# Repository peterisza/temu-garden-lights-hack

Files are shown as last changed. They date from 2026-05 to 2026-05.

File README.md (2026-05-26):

# Temu garden lights hack

I bought 12V-24V outdoor garden lights from Temu. Originally, they had two wires and a remote controller. I modified them to use an addressable three-wire bus (0V, data, 24V) to control them from my smart home. <a href="https://www.youtube.com/shorts/Vp0UermeDtU">Here</a>'s a short youtube video that shows the process and the result. 

Disclaimer: All electrical modifications are performed at your own risk.

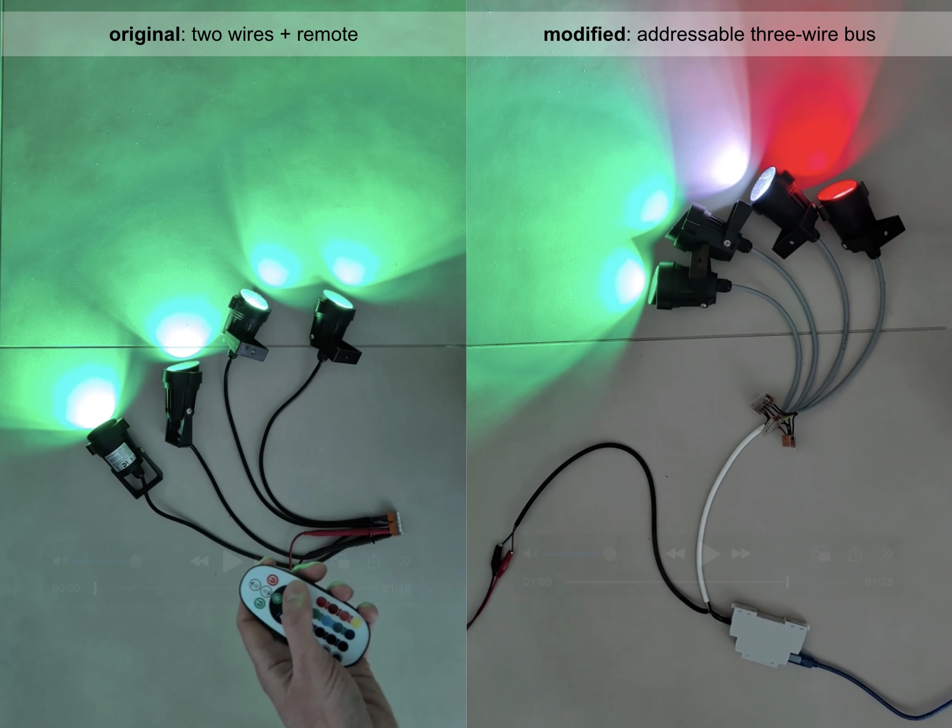
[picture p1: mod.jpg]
Modification


### Reverse engineering the lamp

<table border="0">
  <tr>
    <td valign="top">
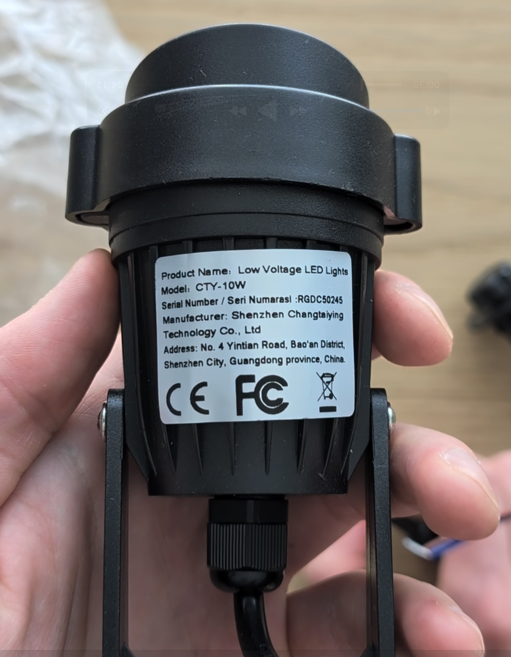
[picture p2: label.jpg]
Product Label
      
    </td>
    <td valign="top">
      <ul>
        <li><strong>Product Name:</strong> Low Voltage LED Lights</li>
        <li><strong>Model:</strong> CTY-10W</li>
        <li><strong>Serial Number / Seri Numarasi:</strong> RGDC50245</li>
        <li><strong>Manufacturer:</strong> Shenzhen Changtaiying Technology Co., Ltd</li>
        <li><strong>Address:</strong> No. 4 Yintian Road, Bao'an District, Shenzhen City, Guangdong province, China.</li>
      </ul>
    </td>
  </tr>
</table>

Originally, the lamp had an FMD FT60E122 microcontroller in an SO-14 package with the following pinout:

<table border="0">
  <th>
    <tr>
      <td>Pinout</td>
      <td>Board&nbsp;image</td>
    </tr>
  </th>
  <tr>
    <td>
      <table>
        <thead>
          <tr><th>#</th><th>Function</th></tr>
        </thead>
        <tbody>
          <tr><td>1</td><td>VDD (5V)</td></tr>
          <tr><td>2</td><td>Crystal1 (16 MHz)</td></tr>
          <tr><td>3</td><td>Crystal2</td></tr>
          <tr><td>4</td><td>radio recv</td></tr>
          <tr><td>5</td><td>Red PWM 62.8μs (10μs max)</td></tr>
          <tr><td>6</td><td>White PWM 62.8μs (49.2μs max)</td></tr>
          <tr><td>7</td><td>not connected</td></tr>
          <tr><td>8</td><td>Green PWM 62.8μs (49.2μs max)</td></tr>
          <tr><td>9</td><td>not connected</td></tr>
          <tr><td>10</td><td>not connected</td></tr>
          <tr><td>11</td><td>Blue PWM 62.8μs (49.2μs max)</td></tr>
          <tr><td>12</td><td>test point 2</td></tr>
          <tr><td>13</td><td>test point 1</td></tr>
          <tr><td>14</td><td>GND</td></tr>
        </tbody>
      </table>
    </td>
    <td valign="top">
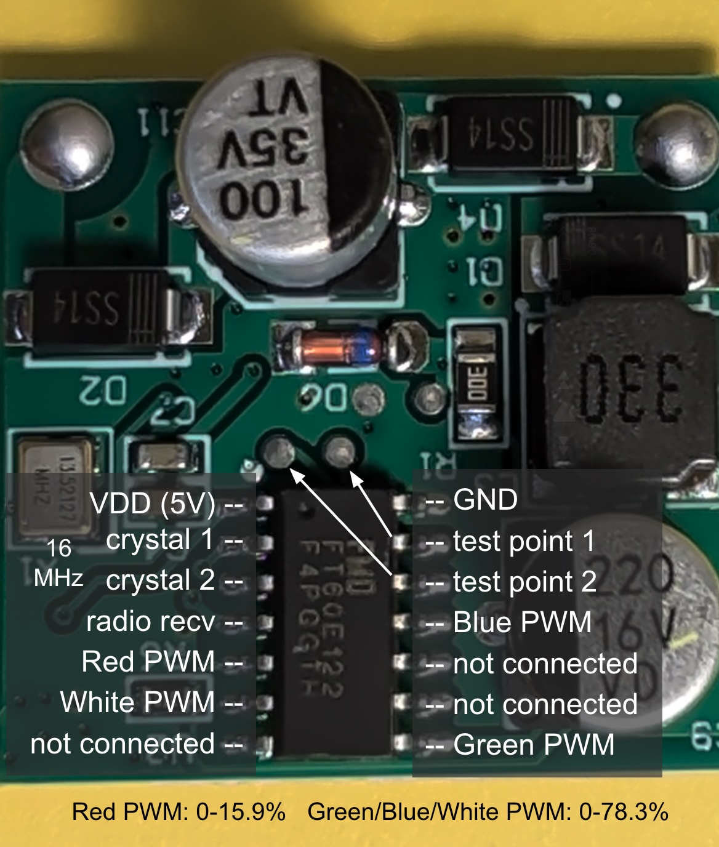
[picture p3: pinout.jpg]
pinout
      
    </td>
  </tr>
</table>

### Conversion

Luckily, this mcu is pin-compatible with the Attiny441. These are the steps I did:

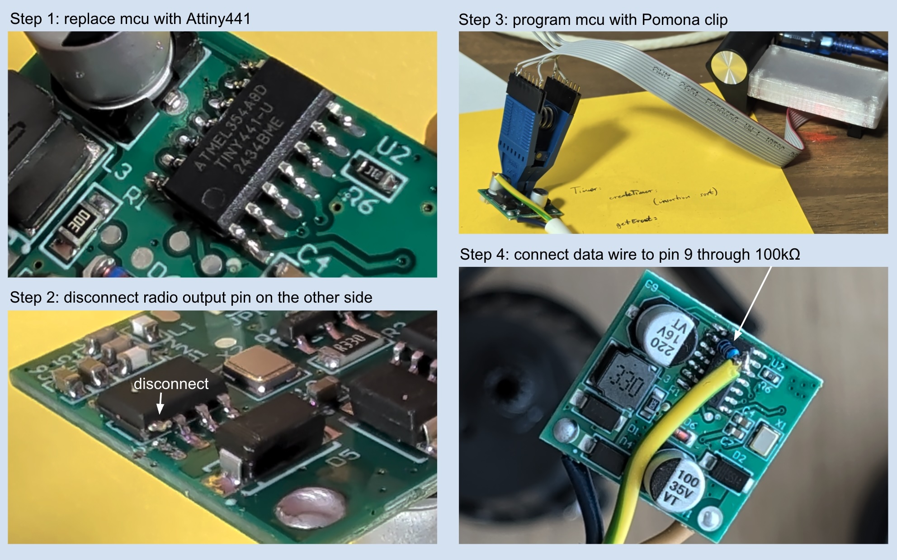
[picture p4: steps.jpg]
Steps


### Custom bus physical description
The custom bus uses three wires: 0V, data, 24V. Logical 0: < 1.5V. Logical 1: 3V-24V. Data format: 10000 baud 8N1. The data line is connected to 24V through a 20mA current limiter in the controller. Max cable length: 200m, number of nodes: 31. To send, each node can pull the data line to zero. Currently, the lamps can only receive but not send. For this reason, their address must be hardcoded during programming like so:
<code>make program LAMP_ADDRESS=0</code>.

I used a 3x0.75mm² ÖLFLEX® CLASSIC 400 P cable. It has the same diameter as the original two-wire cable, but is actually certified for outdoor use unlike the original.

### Data Frame Formats
| Size [byte] | Format A | Size [byte] | Format B |
| :---: | :--- | :---: | :--- |
| 1 | 0 < length <= 30 | 1 | length + 32 |
| max 60 | 4x4 bit RGBW | max 30 | 2x4 bit RGBW |
| 2 | fade time in ms | 2 | fade time in ms |
| 1 | brightness | 1 | brightness |
| 1 | CRC | 1 | CRC |

There must be a 2ms pause between frames.

### Colors

The firmware uses a 16kHz PWM with sigma-delta dithering. It can do gamma-correct interpolation, so the perceived brightness is linear between transitions (premium fade effect 🤩).

### The controller
The controller is a DIN rail mounted USB HID device with a cheap STM32C071 mcu. It can handle two bus lines with 30 lamps each. Build/use it at your own risk only.

My smart home server is already a Raspberry Pi which has USB, so I can just connect it. If you want standalone operation or wireless, you should build an ESP32-based controller instead of this STM32-based one.

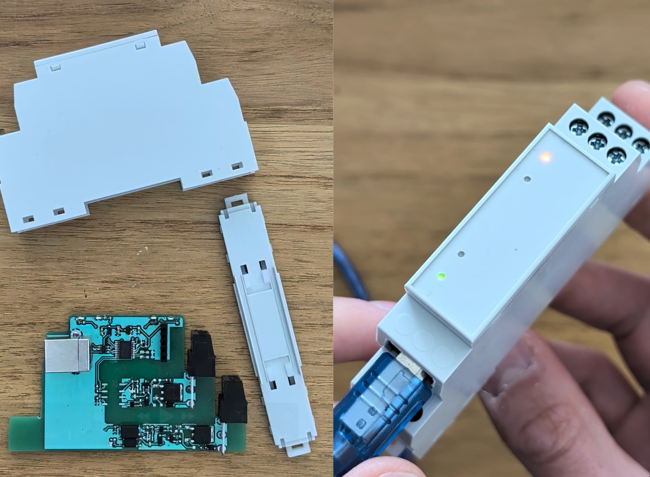
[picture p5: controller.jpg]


## Licensing

- **Software:** Licensed under the [MIT License](https://opensource.org/license/mit)
- **Hardware & Documentation:** Licensed under [CERN-OHL-P](https://ohwr.org/project/cernohl/wikis/Documents/CERN-OHL-version-2) / [CC-BY-4.0](https://creativecommons.org/licenses/by/4.0/)

Basically: feel free to use, modify, and share this project, but keep the attribution and don't sue me if something breaks.

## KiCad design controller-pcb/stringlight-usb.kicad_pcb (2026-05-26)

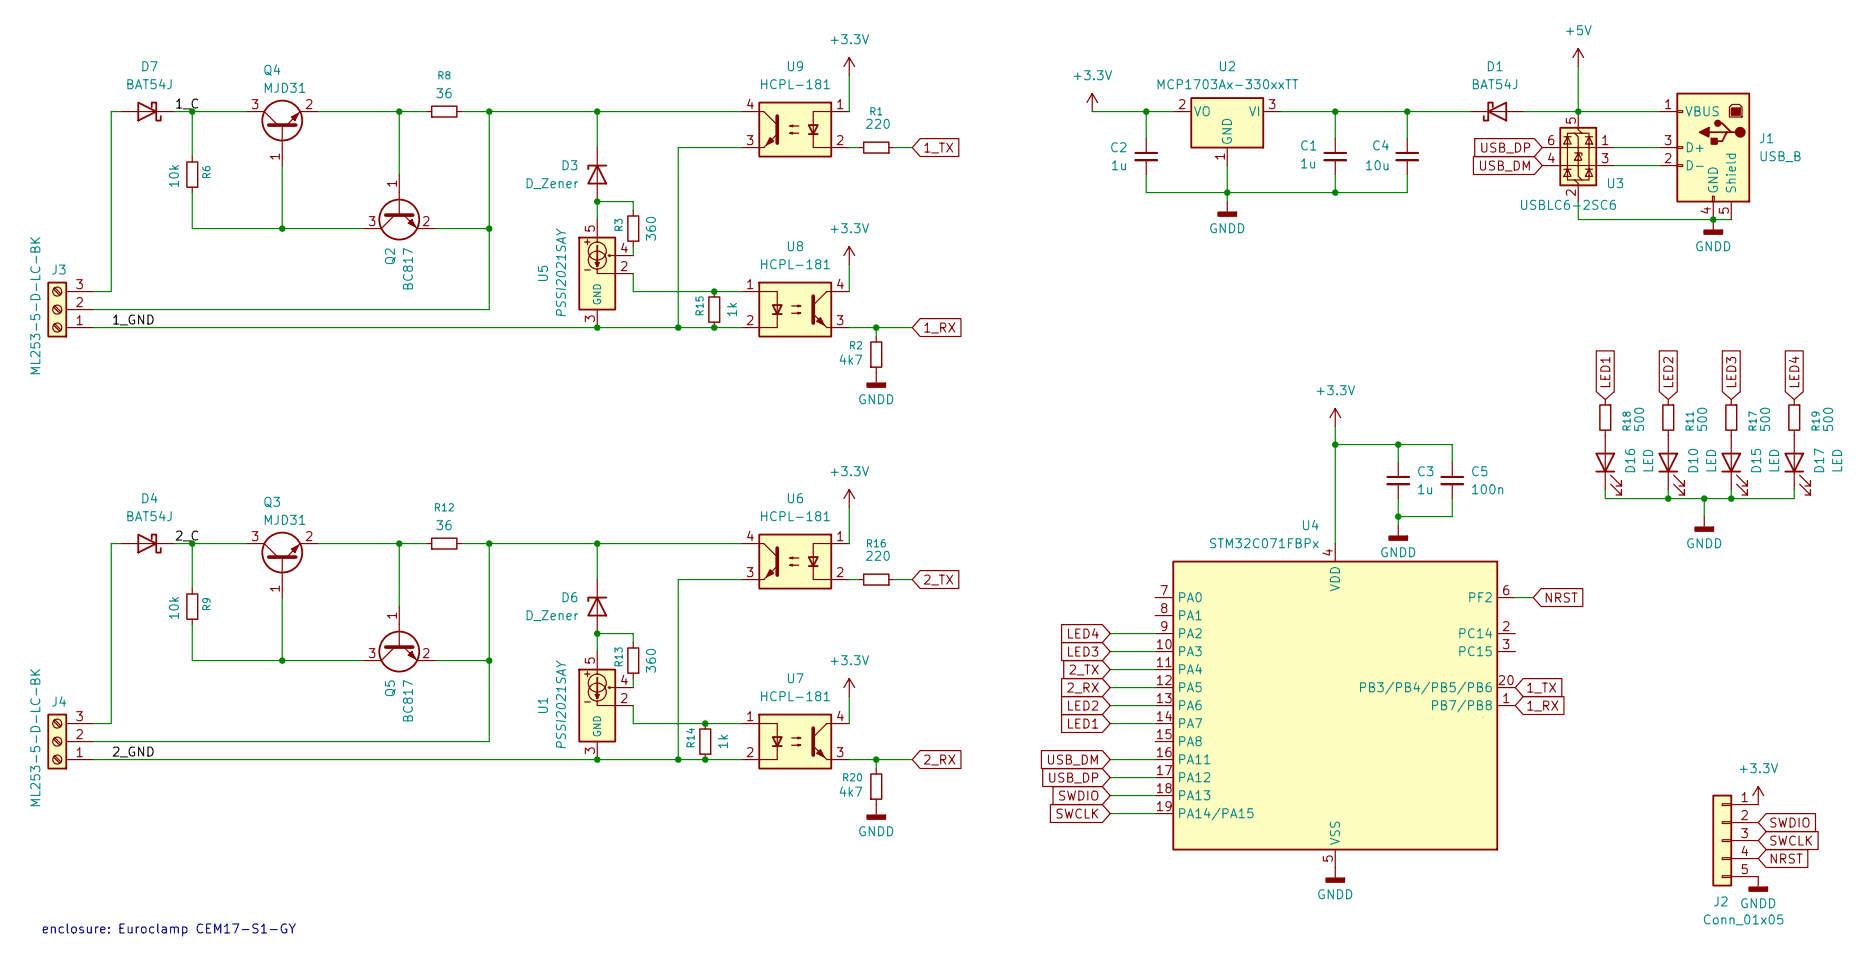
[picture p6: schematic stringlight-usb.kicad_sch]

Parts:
C1, C2, C3: 1u; C_0603_1608Metric_Pad1.08x0.95mm_HandSolder
C4: 10u; C_0805_2012Metric_Pad1.18x1.45mm_HandSolder
C5: 100n; C_0603_1608Metric_Pad1.08x0.95mm_HandSolder
D1, D4, D7: BAT54J; D_SOD-323_HandSoldering
D3, D6: D_Zener; D_SOD-123F
D10, D15, D16, D17: LED; LED_Kingbright_APA1606_1.6x0.6mm_Horizontal
J1: USB_B; USB_B_Lumberg_2411_02_Horizontal
J2: Conn_01x05; PinHeader_1x05_P2.54mm_Vertical
J3, J4: ML253-5-D-LC-BK; ML253-5-S-LC
Q2, Q5: BC817; SOT-23
Q3, Q4: MJD31
R1, R16: 220; R_0603_1608Metric_Pad0.98x0.95mm_HandSolder
R2, R20: 4k7; R_0603_1608Metric_Pad0.98x0.95mm_HandSolder
R3, R13: 360; R_0603_1608Metric_Pad0.98x0.95mm_HandSolder
R6, R9: 10k; R_0603_1608Metric_Pad0.98x0.95mm_HandSolder
R8, R12: 36; R_0603_1608Metric_Pad0.98x0.95mm_HandSolder
R11, R17, R18, R19: 500; R_0603_1608Metric_Pad0.98x0.95mm_HandSolder
R14, R15: 1k; R_0603_1608Metric_Pad0.98x0.95mm_HandSolder
U1, U5: PSSI2021SAY; SOT-353_SC-70-5
U2: MCP1703Ax-330xxTT; SOT-23
U3: USBLC6-2SC6; SOT-23-6
U4: STM32C071FBPx; TSSOP-20_4.4x6.5mm_P0.65mm
U6, U7, U8, U9: HCPL-181; SO-4_4.4x3.6mm_P2.54mm

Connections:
1_RX: R2.2, U4.1 (PB7/PB8), U8.3
1_TX: R1.1, U4.20 (PB3/PB4/PB5/PB6)
2_RX: R20.2, U4.12 (PA5), U7.3
2_TX: R16.1, U4.11 (PA4)
+3.3V: C2.1, C3.1, C5.1, J2.1, U2.2 (VO), U4.4 (VDD), U6.1, U7.4, U8.4, U9.1
+5V: D1.2 (A), J1.1 (VBUS), U3.5 (VBUS)
/1_C: D7.1 (K), Q4.3 (C), R6.2
/1_GND: J3.1, R15.1, U5.3 (GND_3), U8.2, U9.3
/2_C: D4.1 (K), Q3.3 (C), R9.2
/2_GND: J4.1, R14.1, U1.3 (GND_3), U6.3, U7.2
GNDD: C1.2, C2.2, C3.2, C4.2, C5.2, D10.1 (K), D15.1 (K), D16.1 (K), D17.1 (K), J1.4 (GND), J1.5 (Shield), J2.5, R2.1, R20.1, U2.1 (GND), U3.2 (GND), U4.5 (VSS)
LED1: R18.1, U4.14 (PA7)
LED2: R11.1, U4.13 (PA6)
LED3: R17.1, U4.10 (PA3)
LED4: R19.1, U4.9 (PA2)
NRST: J2.4, U4.6 (PF2)
unnamed: C1.1, C4.1, D1.1 (K), U2.3 (VI)
unnamed: D3.2 (A), R3.2, U5.5
unnamed: D3.1 (K), J3.2, Q2.2 (E), R8.2, U9.4
unnamed: D4.2 (A), J4.3
unnamed: D6.2 (A), R13.2, U1.5
unnamed: D6.1 (K), J4.2, Q5.2 (E), R12.2, U6.4
unnamed: D7.2 (A), J3.3
unnamed: D10.2 (A), R11.2
unnamed: D15.2 (A), R17.2
unnamed: D16.2 (A), R18.2
unnamed: D17.2 (A), R19.2
unnamed: J1.3 (D+), U3.1 (I/O1)
unnamed: J1.2 (D-), U3.3 (I/O2)
unnamed: Q2.1 (B), Q4.2 (E), R8.1
unnamed: Q2.3 (C), Q4.1 (B), R6.1
unnamed: Q3.1 (B), Q5.3 (C), R9.1
unnamed: Q3.2 (E), Q5.1 (B), R12.1
unnamed: R1.2, U9.2
unnamed: R3.1, U5.4
unnamed: R13.1, U1.4
unnamed: R14.2, U1.2, U7.1
unnamed: R15.2, U5.2, U8.1
unnamed: R16.2, U6.2
SWCLK: J2.3, U4.19 (PA14/PA15)
SWDIO: J2.2, U4.18 (PA13)
USB_DM: U3.4 (I/O2), U4.16 (PA11)
USB_DP: U3.6 (I/O1), U4.17 (PA12)

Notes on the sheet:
enclosure: Euroclamp CEM17-S1-GY

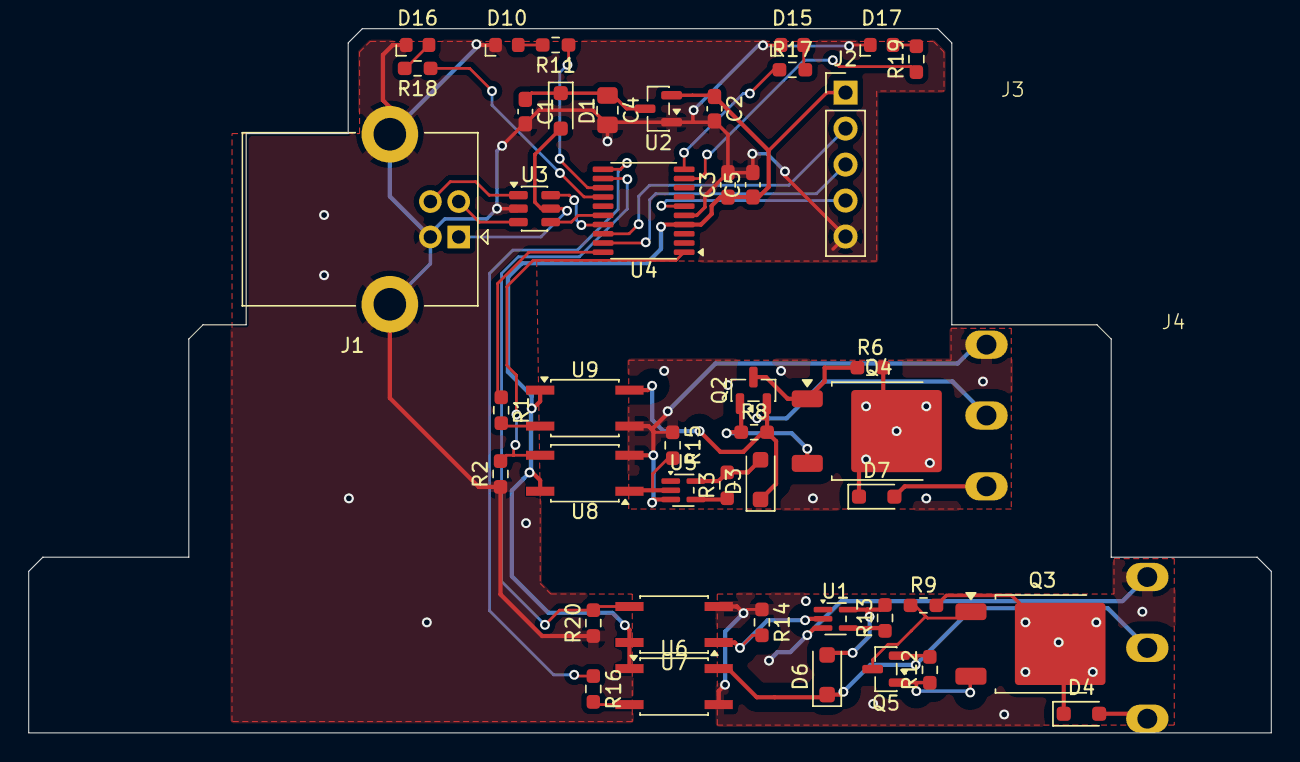
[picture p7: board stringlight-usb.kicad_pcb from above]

Board: 2 copper layers, 87.7 x 49.7 mm, 47 parts (0 on the bottom side), 43 nets.

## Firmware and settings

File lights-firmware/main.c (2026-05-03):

// Attiny441

#define F_CPU 16000000UL
#include <avr/io.h>
#include <avr/interrupt.h>
#include <avr/pgmspace.h>
#include <util/delay.h>
#include <stdint.h>

#define S16_TO_S32_SHIFT(x) ((int32_t)(x) >> 16)
#define U8_TO_U16(x) ((uint16_t)(x))
#define U8_TO_U16_SHIFT(x) ((uint16_t)(x) << 8)

#ifndef LAMP_ADDRESS
#error "LAMP_ADDRESS nincs definialva. Forditsd igy: -DLAMP_ADDRESS=<0..255> (Makefile: LAMP_ADDRESS=...)"
#endif

static const uint8_t bus_address = (uint8_t)(LAMP_ADDRESS);

void io_init() {
	// --- PWM kimenet (PA5 / TOCC4) ---

	DDRA |= (1 << PA3); // PA3 kimenet
	DDRA &= ~(1 << PA4);

	// 1. Lábak kimenetként (PB2, PA7, PA2, PA5)
	DDRA |= (1 << DDA7) | (1 << DDA5) | (1 << DDA2);
	DDRB |= (1 << DDB2);
    
	//PORTA |= (1 << PA4);
}

/* Timer1 overflow tick: Fast PWM-nél f_ov = F_CPU / (TOP+1). A PWM_MAX úgy van választva,
   hogy a korábbi phase-correct időalap (4 tick/ms) megmaradjon. */
static volatile uint8_t g_t1_ticks;
static volatile uint8_t g_last_rx_tick;

static void timer0_init_1ms(void) {
	PRR &= ~(1 << PRTIM0);

	/* CTC: TOP = OCR0A, compare match A interrupt
	   16 MHz, prescaler 64 => 250 kHz tick => OCR0A=249 => 1 kHz (1 ms) */
	TCCR0A = (1 << WGM01);
	TCCR0B = (1 << CS01) | (1 << CS00);
	OCR0A = 249;
	TCNT0 = 0;
	TIFR0 = (1 << OCF0A);
	TIMSK0 |= (1 << OCIE0A);
}

/* TCNT0/1/2 = 0 futó órával is rendben; cli a 16 bites TCNT1/2 írás miatt kell (TEMP regiszter).
 * A TIFR flag bitek ettől nem törlődnek — ha zavar a régi beakadás, azt külön kell 1-gyel írni. */
void timers_sync_counters_zero(void) {
	uint8_t sreg = SREG;
	cli();
	TCNT0 = 0;
	TCNT1 = 0;
	TCNT2 = 0;
	SREG = sreg;
}

/* Fast PWM TOP = PWM_MAX => periódus (tick) = (PWM_MAX+1) CPU ciklus prescaler=1-nél */
#define PWM_MAX 1000U
#define PWM_DITHERING_BITS 4
#define PWM_DITHERING_FACTOR (1 << PWM_DITHERING_BITS)
#define UART_SILENCE_TICKS_2MS (4U)

#define NUM_CHANNELS 4

#define PWM_CHANNEL_RED 0
#define PWM_CHANNEL_GREEN 1
#define PWM_CHANNEL_BLUE 2
#define PWM_CHANNEL_WHITE 3

volatile uint16_t pwm_output[NUM_CHANNELS] = {0, 0, 0, 0};
volatile uint16_t pwm_output_dithered[NUM_CHANNELS] = {0, 0, 0, 0};
volatile uint8_t pwm_fraction[NUM_CHANNELS] = {0, 0, 0, 0};
volatile uint8_t pwm_error[NUM_CHANNELS] = {0, 0, 0, 0};

volatile int32_t channels[NUM_CHANNELS];
volatile int32_t targets[NUM_CHANNELS];
volatile int32_t step[NUM_CHANNELS];

volatile int32_t brightness = 0;
volatile int32_t brightness_target = 0;
volatile int32_t brightness_step = 0;

static const uint16_t channel_max[NUM_CHANNELS] = {
	160U,
	780U,
	780U,
	780U,
};


void set_pwm_registers() {
	OCR1A = pwm_output_dithered[PWM_CHANNEL_RED];
	OCR1B = pwm_output_dithered[PWM_CHANNEL_WHITE];
	OCR2A = pwm_output_dithered[PWM_CHANNEL_BLUE];
	OCR2B = pwm_output_dithered[PWM_CHANNEL_GREEN];
	TCCR1A = (TCCR1A & (uint8_t)~((1 << COM1A1) | (1 << COM1B1)))
		| (pwm_output_dithered[PWM_CHANNEL_RED] != 0 ? (1 << COM1A1) : 0) | (pwm_output_dithered[PWM_CHANNEL_WHITE] != 0 ? (1 << COM1B1) : 0);
	TCCR2A = (TCCR2A & (uint8_t)~((1 << COM2A1) | (1 << COM2B1)))
		| (pwm_output_dithered[PWM_CHANNEL_BLUE] != 0 ? (1 << COM2A1) : 0) | (pwm_output_dithered[PWM_CHANNEL_GREEN] != 0 ? (1 << COM2B1) : 0);
}


void pwm_init() {
	// 2. TOCP Pin Mux beállítása (Timer kimenetek lábakhoz rendelése)
	// TOCC7:OC1A, TOCC6:OC1B, TOCC4:OC2B, TOCC1:OC2A
	TOCPMSA1 = (0<<TOCC7S1) | (1<<TOCC7S0) | (0<<TOCC6S1) | (1<<TOCC6S0) | (1<<TOCC4S1) | (0<<TOCC4S0);
	TOCPMSA0 = (1<<TOCC1S1) | (0<<TOCC1S0);

	// TOCC kimenetek engedélyezése
	TOCPMCOE = (1<<TOCC7OE) | (1<<TOCC6OE) | (1<<TOCC4OE) | (1<<TOCC1OE);

	// 3. Timer1 beállítása (PB2 és PA7) - Fast PWM, Mode 14, TOP = ICR1
	TCCR1A = (1 << COM1A1) | (1 << COM1B1) | (1 << WGM11);
	TCCR1B = (1 << WGM13) | (1 << WGM12) | (1 << CS10);
	ICR1 = PWM_MAX-1;
	TIMSK1 |= (1 << TOIE1); /* időalap: TIMER1_OVF_vect */

	// 4. Timer2 beállítása (PA2 és PA5) - Fast PWM, TOP = ICR2 (WGM2[2:0]=111)
	TCCR2A = (1 << COM2A1) | (1 << COM2B1) | (1 << WGM21) | (1 << WGM20);
	TCCR2B = (1 << WGM22) | (1 << CS20);
	ICR2 = PWM_MAX-1;

	// 5. Példa kitöltési tényezők (0 - 500 tartományban)
	set_pwm_registers();
}




#define UART_BUFFER_SIZE 70
static volatile uint8_t uart_buffer[UART_BUFFER_SIZE];
static volatile uint8_t uart_buffer_length;

/* CRC-8/ATM (poly 0x07, init 0x00, no xorout), table-driven, MSB-first */
static const uint8_t crc8_atm_table[256] PROGMEM = {
	0x00, 0x07, 0x0E, 0x09, 0x1C, 0x1B, 0x12, 0x15, 0x38, 0x3F, 0x36, 0x31, 0x24, 0x23, 0x2A, 0x2D,
	0x70, 0x77, 0x7E, 0x79, 0x6C, 0x6B, 0x62, 0x65, 0x48, 0x4F, 0x46, 0x41, 0x54, 0x53, 0x5A, 0x5D,
	0xE0, 0xE7, 0xEE, 0xE9, 0xFC, 0xFB, 0xF2, 0xF5, 0xD8, 0xDF, 0xD6, 0xD1, 0xC4, 0xC3, 0xCA, 0xCD,
	0x90, 0x97, 0x9E, 0x99, 0x8C, 0x8B, 0x82, 0x85, 0xA8, 0xAF, 0xA6, 0xA1, 0xB4, 0xB3, 0xBA, 0xBD,
	0xC7, 0xC0, 0xC9, 0xCE, 0xDB, 0xDC, 0xD5, 0xD2, 0xFF, 0xF8, 0xF1, 0xF6, 0xE3, 0xE4, 0xED, 0xEA,
	0xB7, 0xB0, 0xB9, 0xBE, 0xAB, 0xAC, 0xA5, 0xA2, 0x8F, 0x88, 0x81, 0x86, 0x93, 0x94, 0x9D, 0x9A,
	0x27, 0x20, 0x29, 0x2E, 0x3B, 0x3C, 0x35, 0x32, 0x1F, 0x18, 0x11, 0x16, 0x03, 0x04, 0x0D, 0x0A,
	0x57, 0x50, 0x59, 0x5E, 0x4B, 0x4C, 0x45, 0x42, 0x6F, 0x68, 0x61, 0x66, 0x73, 0x74, 0x7D, 0x7A,
	0x89, 0x8E, 0x87, 0x80, 0x95, 0x92, 0x9B, 0x9C, 0xB1, 0xB6, 0xBF, 0xB8, 0xAD, 0xAA, 0xA3, 0xA4,
	0xF9, 0xFE, 0xF7, 0xF0, 0xE5, 0xE2, 0xEB, 0xEC, 0xC1, 0xC6, 0xCF, 0xC8, 0xDD, 0xDA, 0xD3, 0xD4,
	0x69, 0x6E, 0x67, 0x60, 0x75, 0x72, 0x7B, 0x7C, 0x51, 0x56, 0x5F, 0x58, 0x4D, 0x4A, 0x43, 0x44,
	0x19, 0x1E, 0x17, 0x10, 0x05, 0x02, 0x0B, 0x0C, 0x21, 0x26, 0x2F, 0x28, 0x3D, 0x3A, 0x33, 0x34,
	0x4E, 0x49, 0x40, 0x47, 0x52, 0x55, 0x5C, 0x5B, 0x76, 0x71, 0x78, 0x7F, 0x6A, 0x6D, 0x64, 0x63,
	0x3E, 0x39, 0x30, 0x37, 0x22, 0x25, 0x2C, 0x2B, 0x06, 0x01, 0x08, 0x0F, 0x1A, 0x1D, 0x14, 0x13,
	0xAE, 0xA9, 0xA0, 0xA7, 0xB2, 0xB5, 0xBC, 0xBB, 0x96, 0x91, 0x98, 0x9F, 0x8A, 0x8D, 0x84, 0x83,
	0xDE, 0xD9, 0xD0, 0xD7, 0xC2, 0xC5, 0xCC, 0xCB, 0xE6, 0xE1, 0xE8, 0xEF, 0xFA, 0xFD, 0xF4, 0xF3,
};

static uint8_t crc8_atm(const volatile uint8_t *data, uint8_t len) {
	uint8_t crc = 0x00;
	for (uint8_t i = 0; i < len; i++) {
		uint8_t idx = (uint8_t)(crc ^ data[i]);
		crc = pgm_read_byte(&crc8_atm_table[idx]);
	}
	return crc;
}

void uart_init(void) {
	/* USART1 RX @ PA4 (RXD1), 10000 baud, 8N1 (polling + buffer) */
	PRR &= ~(1 << PRUSART1);

	/* 16 MHz: baud = F_CPU / (16 * (UBRR+1)) => UBRR = 99 pontosan 10000 baud */
	UBRR1 = 99;
	UCSR1A = 0; /* U2X1=0 */

	/* 8N1 */
	UCSR1C = (1 << UCSZ11) | (1 << UCSZ10);
	UCSR1B = (1 << RXEN1);
}

const uint16_t gamma_lut[16] PROGMEM = {
	0,   21,   97,  237,  447,  731, 1091, 1532, 2055, 2662, 3357, 4140,
 5013, 5979, 7037, 8191
};


void update_pwm(void) {
	uint32_t c[NUM_CHANNELS];
	for (uint8_t i = 0; i < NUM_CHANNELS; i++) {
		c[i] = (uint32_t)(channels[i] >> 16);
	}
	uint32_t sum = c[0] + c[1] + c[2] + 3 * c[3];
	uint32_t sum_target = brightness >> 8;
	sum_target *= sum_target;
	sum_target >>= 16;

	if (sum == 0) {
		sum = 1;
	}

	for (uint8_t i = 0; i < NUM_CHANNELS; i++) {
		uint32_t norm = c[i] * sum_target / sum;
		uint16_t pwm = (uint16_t)((norm * channel_max[i]) >> (13 - PWM_DITHERING_BITS));
		pwm_fraction[i] = (uint8_t)(pwm & (PWM_DITHERING_FACTOR - 1));
		pwm_output[i] = (uint16_t)(pwm >> PWM_DITHERING_BITS);
		if(pwm_output[i] > channel_max[i]) {
			pwm_output[i] = channel_max[i];
		}
	}
}

volatile int16_t color_transition_counter = 0;

ISR(TIMER1_OVF_vect) {
	set_pwm_registers();

	for (uint8_t i = 0; i < NUM_CHANNELS; i++) {
		pwm_error[i] += pwm_fraction[i];
		if (pwm_error[i] >= PWM_DITHERING_FACTOR) {
			pwm_output_dithered[i] = pwm_output[i] + 1;
			pwm_error[i] -= PWM_DITHERING_FACTOR;
		} else {
			pwm_output_dithered[i] = pwm_output[i];
		}
	}
}

ISR(TIMER0_COMPA_vect, ISR_NOBLOCK) {
	g_t1_ticks++;

	if (color_transition_counter > 0) {
		color_transition_counter--;
		for (uint8_t i = 0; i < NUM_CHANNELS; i++) {
			channels[i] += step[i];
		}
		brightness += brightness_step;
		if (color_transition_counter == 0) {
			for (uint8_t i = 0; i < NUM_CHANNELS; i++) {
				channels[i] = targets[i];
			}
			brightness = brightness_target;
		}
		update_pwm();
	}
}


uint16_t sqrt32(uint32_t n) {
    uint32_t root = 0;
    uint32_t bit = 1UL << 30; // A legmagasabb bitpárral kezdünk

    // Megkeressük a legnagyobb 4 hatványt, ami kisebb vagy egyenlő 'n'-nél
    while (bit > n) {
        bit >>= 2;
    }

    // Bitenkénti közelítés
    while (bit != 0) {
        if (n >= root + bit) {
            n -= root + bit;
            root = (root >> 1) + bit;
        } else {
            root >>= 1;
        }
        bit >>= 2;
    }

    return (uint16_t)root;
}

void set_color_target(uint8_t r, uint8_t g, uint8_t b, uint8_t w, uint8_t brightness_factor, int16_t time)
{
	r &= 0x0F;
	g &= 0x0F;
	b &= 0x0F;
	w &= 0x0F;

	uint32_t raw[NUM_CHANNELS] = {
		(uint32_t)pgm_read_word(&gamma_lut[r]),
		(uint32_t)pgm_read_word(&gamma_lut[g]),
		(uint32_t)pgm_read_word(&gamma_lut[b]),
		(uint32_t)pgm_read_word(&gamma_lut[w]),
	};	

	color_transition_counter = 0;

	uint32_t sum = raw[0] + raw[1] + raw[2] + 3 * raw[3];
	uint32_t norm = (uint32_t)sqrt32(sum << 16) * brightness_factor;

	brightness_target = (int32_t)norm;
	if(time <= 2) {
		for(uint8_t i = 0; i < NUM_CHANNELS; i++) {
			channels[i] = raw[i] << 16;
		}
		brightness = brightness_target;
		update_pwm();
	} else {
		int32_t time_half = time / 2;
		int32_t time_32 = time;
		for (uint8_t i = 0; i < NUM_CHANNELS; i++) {
			targets[i] = (int32_t)(raw[i] << 16);
			step[i] = targets[i] - channels[i];
			step[i] = (step[i] + time_half) / time_32;
			//step[i] = 0;
		}
		brightness_step = brightness_target - brightness;
		brightness_step = (brightness_step + time_half) / time_32;
		//brightness_step = 0;
		color_transition_counter = time;
	}
}

void uart_process_buffer(void) {
	/* CRC-8: az utolsó bájt a várt CRC */
	if (uart_buffer_length < 2) {
		return;
	}

	uint8_t expected = uart_buffer[uart_buffer_length - 1];
	uint8_t computed = crc8_atm(uart_buffer, uart_buffer_length - 1);

	if (computed != expected) {
		return;
	}

	uint8_t main_byte = uart_buffer[0];
	if(main_byte <= 31) {
		uint8_t length = main_byte + 1;
		if(uart_buffer_length != length * 2 + 5)
			return;
		if(bus_address >= length)
			return;
		uint8_t offset = bus_address * 2 + 1;
		set_color_target(
			uart_buffer[offset] & 0x0F,
			uart_buffer[offset] >> 4,
			uart_buffer[offset + 1] & 0x0F,
			uart_buffer[offset + 1] >> 4,
			uart_buffer[uart_buffer_length - 2],
			(int16_t)(U8_TO_U16(uart_buffer[uart_buffer_length - 3]) + U8_TO_U16_SHIFT(uart_buffer[uart_buffer_length - 4]))
		);
	} else if(main_byte <= 63) {
		uint8_t length = main_byte - 32 + 1;
		if(uart_buffer_length != length + 5)
			return;
		if(bus_address >= length)
			return;
		uint8_t offset = bus_address + 1;
		set_color_target(
			(uart_buffer[offset] & 0x03) * 5,
			((uart_buffer[offset] >> 2) & 0x03) * 5,
			((uart_buffer[offset] >> 4) & 0x03) * 5,
			(uart_buffer[offset] >> 6) * 5,
			uart_buffer[uart_buffer_length - 2],
			(int16_t)(U8_TO_U16(uart_buffer[uart_buffer_length - 3]) + U8_TO_U16_SHIFT(uart_buffer[uart_buffer_length - 4]))
		);

	} else if(main_byte == 64) { // new bus address
		/* bus_address fixen fordításkor van beégetve -> ignore */
	} else if(main_byte == 65) { // clear bus address
		/* bus_address fixen fordításkor van beégetve -> ignore */
	}

}

int main(void) {
	io_init();

	_delay_us(2*LAMP_ADDRESS);

	pwm_init();
	timer0_init_1ms();
	uart_init();
	timers_sync_counters_zero();
	sei();

	update_pwm();
	while (1) {
		/* UART polling: ha van bájt, tedd pufferbe és frissítsd a last_rx időt */
		if (UCSR1A & (1 << RXC1)) {
			if (uart_buffer_length < UART_BUFFER_SIZE) {
				uart_buffer[uart_buffer_length] = UDR1;
				uart_buffer_length++;
			}
			g_last_rx_tick = g_t1_ticks;
		}

		/* Ha 2ms-ig nem jött új bájt és van mit feldolgozni */
		if (uart_buffer_length > 0 && (uint8_t)(g_t1_ticks - g_last_rx_tick) >= (uint8_t)UART_SILENCE_TICKS_2MS) {
			uart_process_buffer();
			uart_buffer_length = 0;
		}
    }
}

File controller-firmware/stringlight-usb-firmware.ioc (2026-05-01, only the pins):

Mcu.UserName=STM32C071FBPx
PA2.Signal=GPIO_Output
PA3.Signal=GPIO_Output
PA4.Signal=USART2_TX
PA5.Signal=USART2_RX
PA6.Signal=GPIO_Output
PA7.Signal=GPIO_Output
PB6.Signal=USART1_TX
PB7.Signal=USART1_RX

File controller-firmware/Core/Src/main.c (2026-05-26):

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
/* Includes ------------------------------------------------------------------*/
#include "main.h"
#include "app_usbx_device.h"

/* USER CODE BEGIN Includes */
#include "verified_uart.h"
#include "status_leds.h"
/* USER CODE END Includes */


UART_HandleTypeDef huart1;
UART_HandleTypeDef huart2;

PCD_HandleTypeDef hpcd_USB_DRD_FS;

/* USER CODE BEGIN PV */
VerifiedUart g_uart2;
/* USER CODE END PV */

void SystemClock_Config(void);
static void MX_GPIO_Init(void);
static void MX_USART1_UART_Init(void);
static void MX_USART2_UART_Init(void);
static void MX_USB_PCD_Init(void);
/**
  * @brief  The application entry point.
  * @retval int
  */
int main(void)
{

  /* MCU Configuration--------------------------------------------------------*/

  /* Reset of all peripherals, Initializes the Flash interface and the Systick. */
  HAL_Init();

  /* Configure the system clock */
  SystemClock_Config();

  /* USER CODE BEGIN SysInit */
  /* CRS Bekapcsolása - Javított verzió STM32C0-hoz */
  __HAL_RCC_CRS_CLK_ENABLE();

  /* A C0-nál a CRS nem az RCC része, hanem külön periféria: CRS->... */
  CRS->CR |= CRS_CR_AUTOTRIMEN; // Automatikus hangolás bekapcsolása
  CRS->CR |= CRS_CR_CEN;        // CRS számláló indítása
  /* USER CODE END SysInit */

  /* Initialize all configured peripherals */
  MX_GPIO_Init();
  MX_USART1_UART_Init();
  MX_USART2_UART_Init();
  //MX_USB_PCD_Init();
  MX_USBX_Device_Init();
  /* USER CODE BEGIN 2 */
  MX_USB_PCD_Init();
  HAL_PCD_DevConnect(&hpcd_USB_DRD_FS); // Ez rántja meg a vonalat a PC-nek
  VerifiedUart_Init(&g_uart2, &huart2);
  VerifiedUart_Start(&g_uart2);
  StatusLeds_Init();
  /* USER CODE END 2 */

  /* Infinite loop */
  /* USER CODE BEGIN WHILE */
  while (1)
  {
	  ux_device_stack_tasks_run();
	  VerifiedUart_Process(&g_uart2);
	  if (VerifiedUart_ConsumeFrameDropEvent(&g_uart2)) {
		  StatusLeds_PulseRed(1000U);
	  }
	  StatusLeds_Update(false, VerifiedUart_IsFault(&g_uart2));
    /* USER CODE END WHILE */

    /* USER CODE BEGIN 3 */
  }
  /* USER CODE END 3 */
}

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
/**
  * @brief  Period elapsed callback in non blocking mode
  * @note   This function is called  when TIM1 interrupt took place, inside
  * HAL_TIM_IRQHandler(). It makes a direct call to HAL_IncTick() to increment
  * a global variable "uwTick" used as application time base.
  * @param  htim : TIM handle
  * @retval None
  */
void HAL_TIM_PeriodElapsedCallback(TIM_HandleTypeDef *htim)
{
  if (htim->Instance == TIM1)
  {
    HAL_IncTick();
  }
}

/**
  * @brief  This function is executed in case of error occurrence.
  * @retval None
  */
void Error_Handler(void)
{
  /* USER CODE BEGIN Error_Handler_Debug */
  /* User can add his own implementation to report the HAL error return state */
  __disable_irq();
  while (1)
  {
  }
  /* USER CODE END Error_Handler_Debug */
}
#ifdef USE_FULL_ASSERT
/**
  * @brief  Reports the name of the source file and the source line number
  *         where the assert_param error has occurred.
  * @param  file: pointer to the source file name
  * @param  line: assert_param error line source number
  * @retval None
  */
void assert_failed(uint8_t *file, uint32_t line)
{
  /* USER CODE BEGIN 6 */
  /* User can add his own implementation to report the file name and line number,
     ex: printf("Wrong parameters value: file %s on line %d\r\n", file, line) */
  /* USER CODE END 6 */
}
#endif /* USE_FULL_ASSERT */

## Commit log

2026-05-02 phase correct PWM -> fast PWM, increased PWM frequency from 1 kHz to 16 kHz, added dithering
    [main.c]
2026-05-03 fixed bug in dithering
    [main.c]
2026-05-26 - speed up opto RX with additional 1k resistor - add firmware-based 24V-data short circuit protection (goes into fault mode)
    [stringlight-usb.kicad_pcb, stringlight-usb.kicad_sch]

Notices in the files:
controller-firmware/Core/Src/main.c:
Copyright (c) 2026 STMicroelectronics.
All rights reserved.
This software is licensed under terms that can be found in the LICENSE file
